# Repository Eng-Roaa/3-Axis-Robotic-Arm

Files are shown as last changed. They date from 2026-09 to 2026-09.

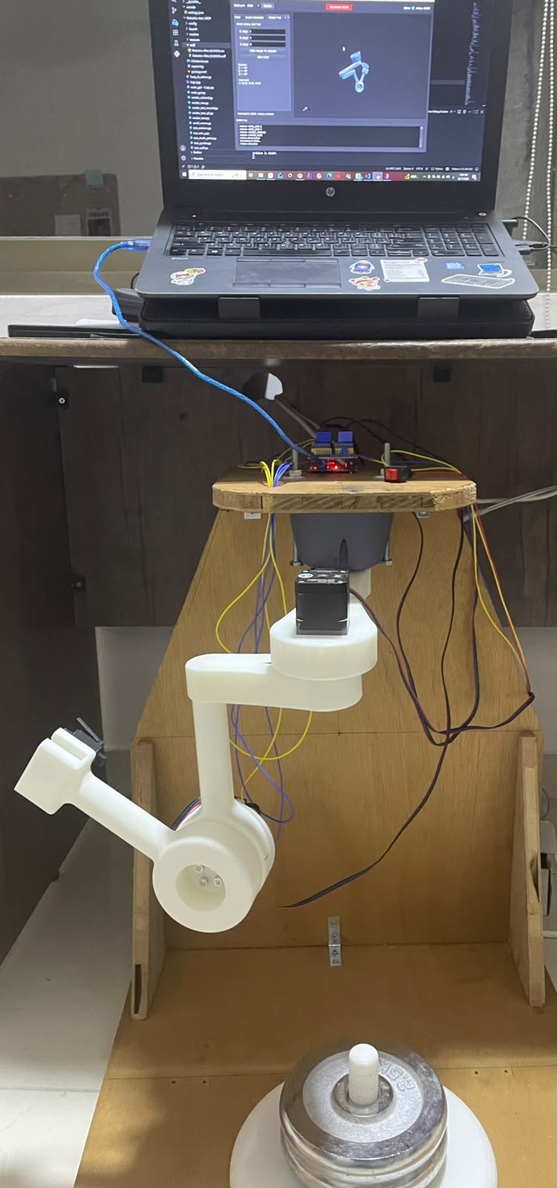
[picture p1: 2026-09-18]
Media/WhatsApp Image 2026-09-18 at 6.12.28 PM.jpeg

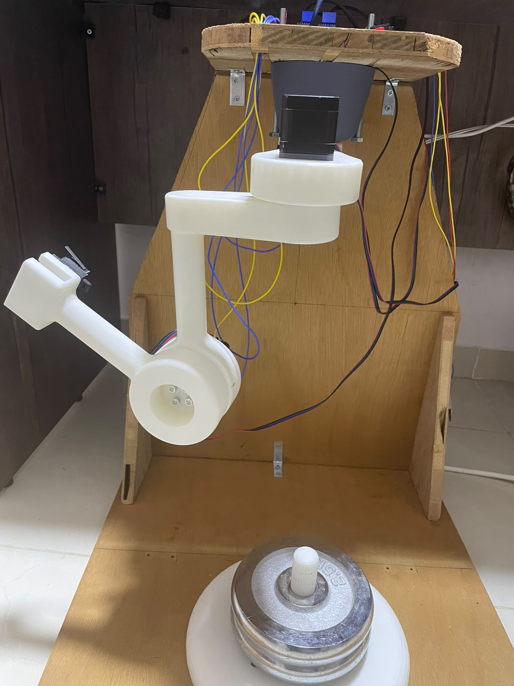
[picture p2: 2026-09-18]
Media/WhatsApp Image 2026-09-18 at 6.12.29 PM.jpeg

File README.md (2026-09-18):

# 3-Axis Robotic Arm | Design, Simulation, and Control 🦾

A 3-axis robotic arm developed as a complete robotics project, covering mechanical design, simulation, kinematics, hardware development, and motion control.

## 📌 Project Overview

The project started with the **CAD design** of the robotic arm and its mechanical components using **SolidWorks**. Before fabrication, the system was tested in a simulation environment to verify the robot's motion and kinematic calculations.

After validating the design and motion, the physical robotic arm was fabricated using **3D printing** and integrated with stepper motors and electronic control components.

## 🔹 CAD Design

The robotic arm and its mechanical components were designed using **SolidWorks**.

The design includes the main arm structure, joints, and **25:1 strain wave gearboxes** used with the stepper motors.

## 🔹 Simulation & Kinematics

A Python-based control system was developed to work with the robotic arm simulation.

The system implements:

* Forward Kinematics (FK)
* Inverse Kinematics (IK)
* Joint position control
* Robot motion simulation

The kinematic calculations were tested before moving to the physical implementation.

## 🔹 Hardware Development

After the simulation and testing stage, the robotic arm components and gearboxes were **3D-printed**.

### Main Hardware

* 3 × NEMA 17 Stepper Motors
* 3 × TMC2208 Stepper Motor Drivers
* CNC Shield V3
* Arduino
* 25:1 Strain Wave Gearboxes
* 3D-printed mechanical components
* 3 Limit switches

## 🔹 Motion Control

The robotic arm is controlled using a **Python application running on a PC**.

Python performs the main calculations, including forward and inverse kinematics, and sends the target joint angles to the **Arduino through serial communication**.

The Arduino then controls the stepper motors according to the received commands.

## 🔹 Synchronized Motion

A synchronized motion mechanism was implemented to ensure that the three motors **start and stop at the same time**, even when different angular movements are required for each joint.

This allows the joints to complete their movements together rather than having one motor finish earlier than the others.

## 🔹 Homing & Limit Switches

A homing procedure was implemented to establish a known starting position for the robotic arm.

**Limit switches** are used to detect the mechanical limits of the joints and stop the corresponding motion when the arm reaches the limit.

## 🛠️ Technologies Used

| Category | Technologies |
| --- | --- |
| CAD | SolidWorks |
| Programming | Python, Arduino/C++ |
| Control | Serial Communication |
| Kinematics | Forward & Inverse Kinematics |
| Motors | NEMA 17 Stepper Motors |
| Drivers | TMC2208 |
| Controller | Arduino + CNC Shield V3 |
| Manufacturing | 3D Printing |

## 📷 Project Media

Project images and videos are available in the `Media` folder.

## 🎥 Project Demonstration

A demonstration video of the robotic arm will be added here.
https://drive.google.com/file/d/13j7fY6XMhpEBEr_zSgsBxvps_PN-o1Ip/view?usp=drive_link

## 🚀 Future Improvements

* Improve positioning accuracy
* Implement smoother trajectory planning
* Add acceleration and deceleration profiles
* Improve the simulation environment
* Develop more advanced motion planning
* Improve the user interface

## 👩‍💻 Author

**Roaa Ghanem**

Biomedical Engineer

---

*This project was developed for educational and practical exploration of robotics, CAD, kinematics, and motion control.*

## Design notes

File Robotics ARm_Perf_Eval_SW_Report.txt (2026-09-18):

The following messages were automatically dismissed when this file was opened

File	Message	Response	

Servo_Motor.SLDPRT	One or more features in this part are based on other documents. If those documents have changed, they should be opened now to properly update this part.	Open any documents which have changed

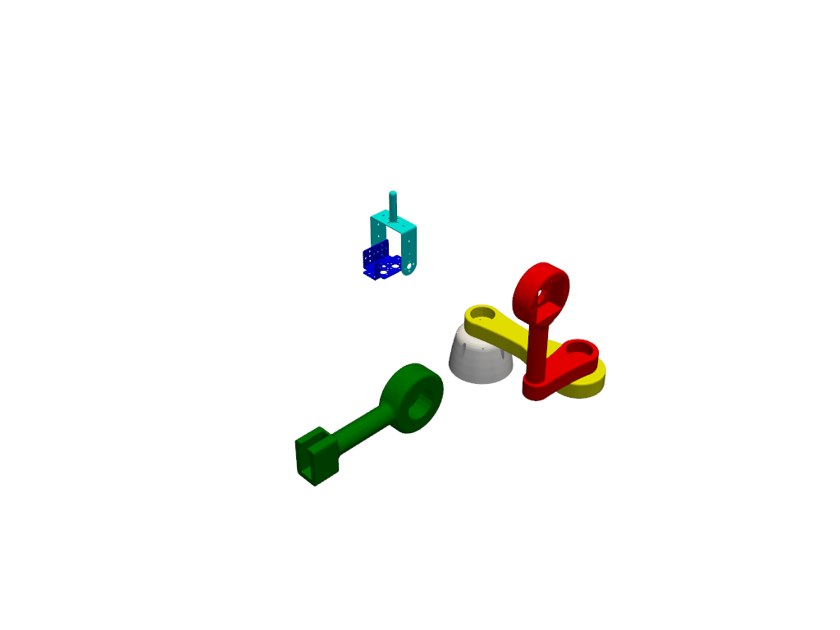
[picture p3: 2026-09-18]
fixed_arm.png

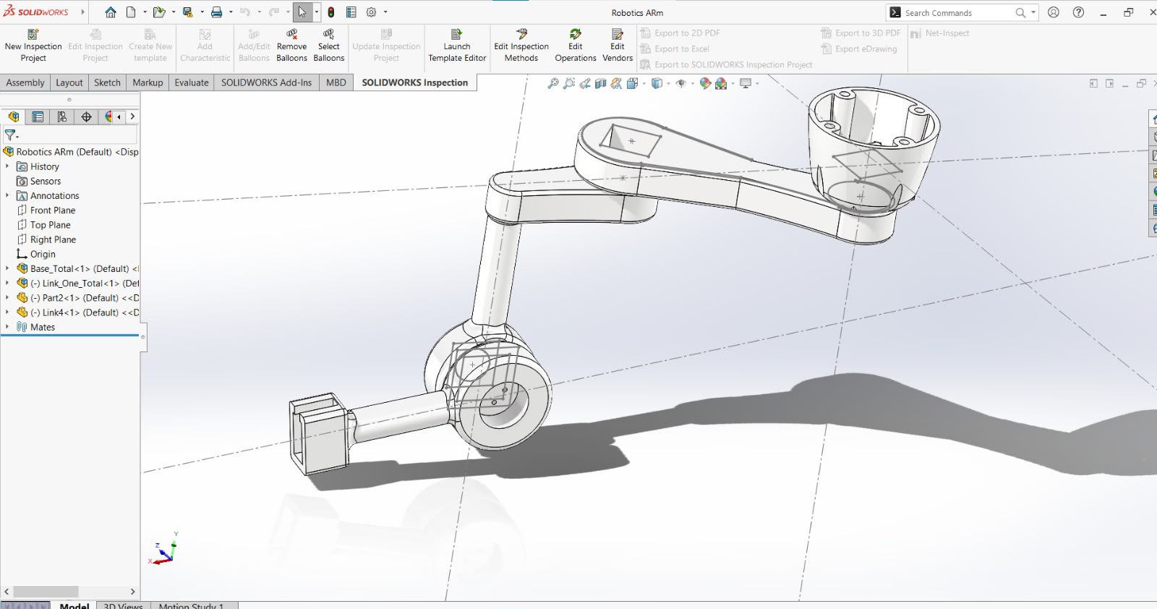
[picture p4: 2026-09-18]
Media/WhatsApp Image 2026-09-18 at 6.11.49 PM.jpeg

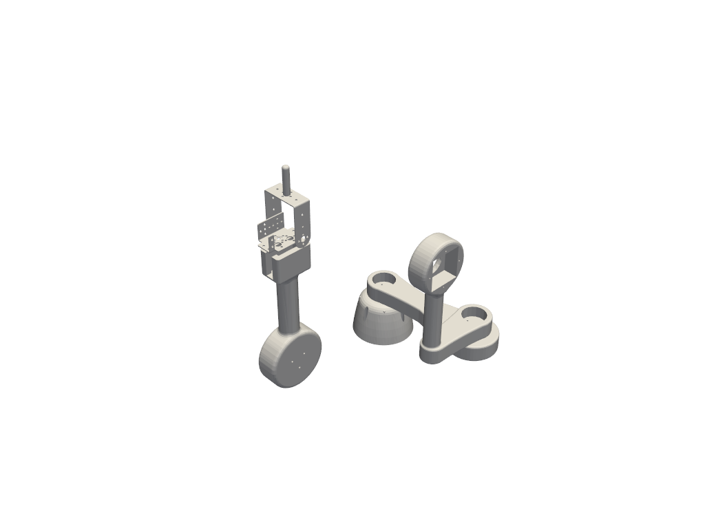
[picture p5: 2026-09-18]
moved_q2.png

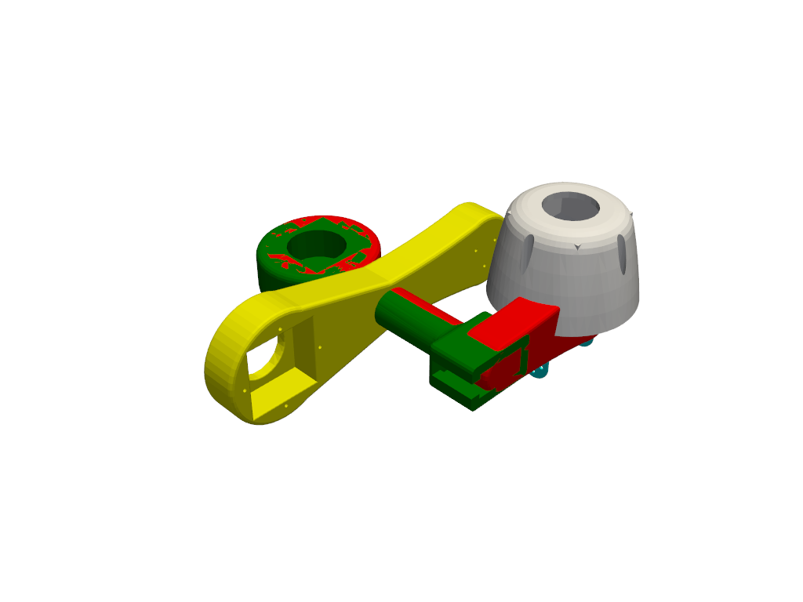
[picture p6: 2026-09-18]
raw_meshes.png

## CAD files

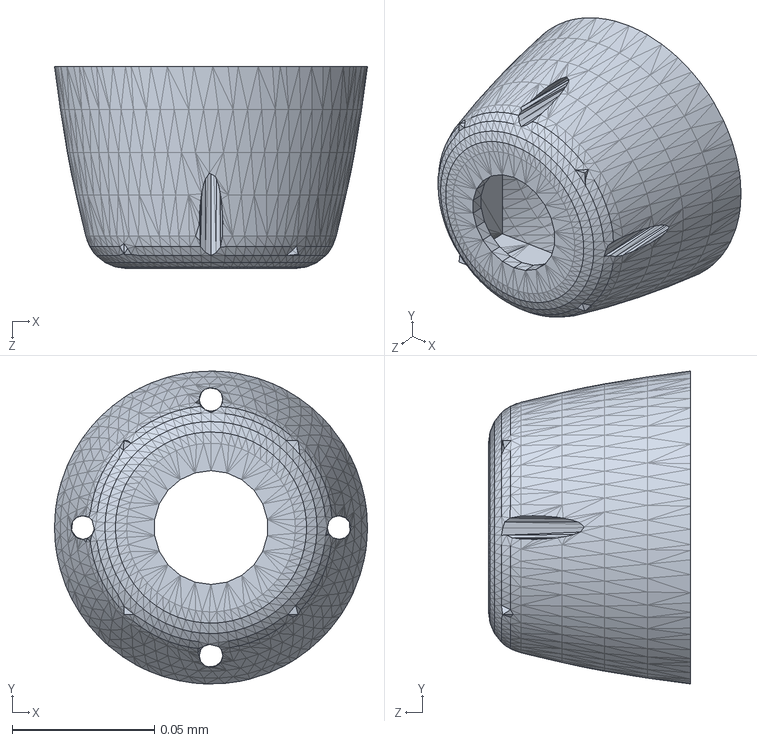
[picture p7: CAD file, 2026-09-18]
base_link.SLDPRT
0.11 x 0.11 x 0.071 mm

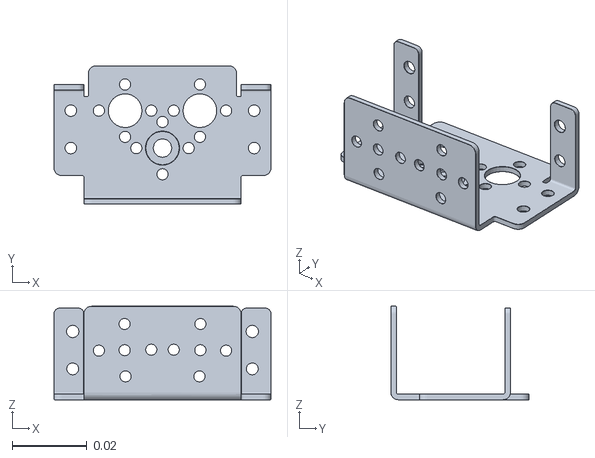
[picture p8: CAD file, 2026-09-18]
Robotics Arm URDF/meshes/Link_4.STL
0.058 x 0.037 x 0.025

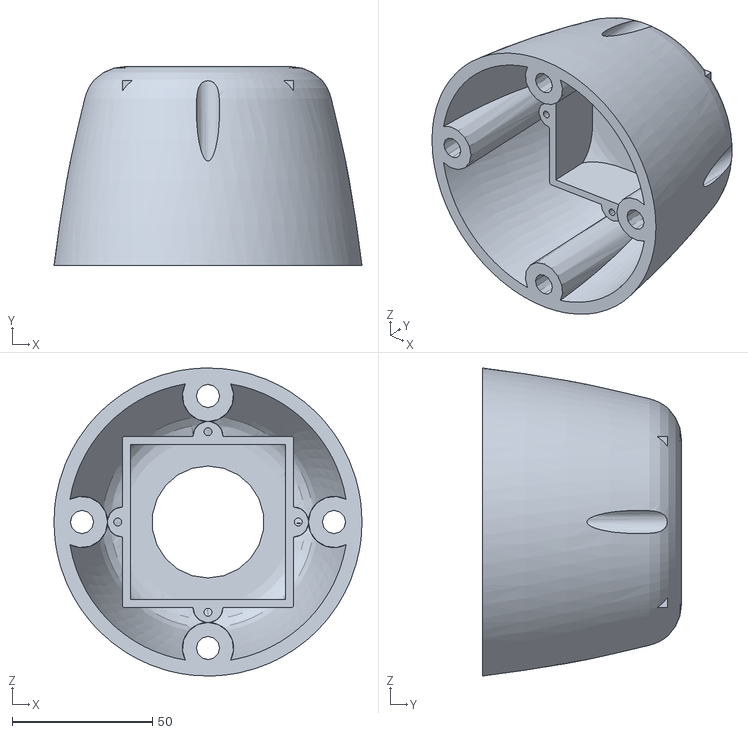
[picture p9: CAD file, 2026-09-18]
STL Files/Base.STL
110.0 x 71.0 x 110.0

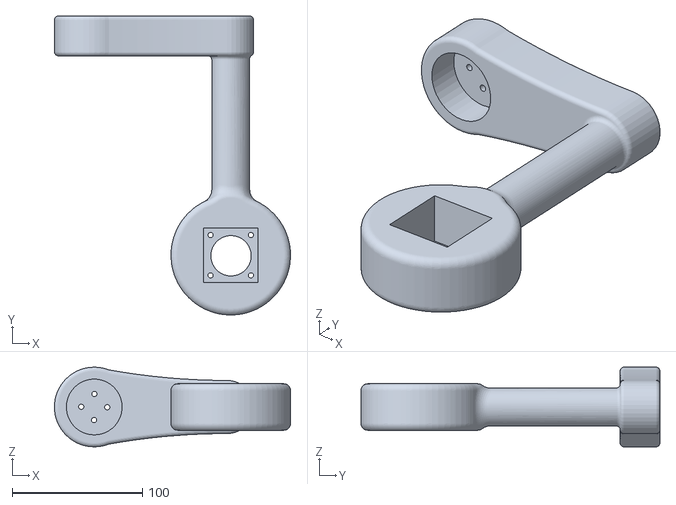
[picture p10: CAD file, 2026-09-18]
STL Files/robotic arm stl Fixed-Printable/Part2.STL
181.2 x 229.5 x 61.2

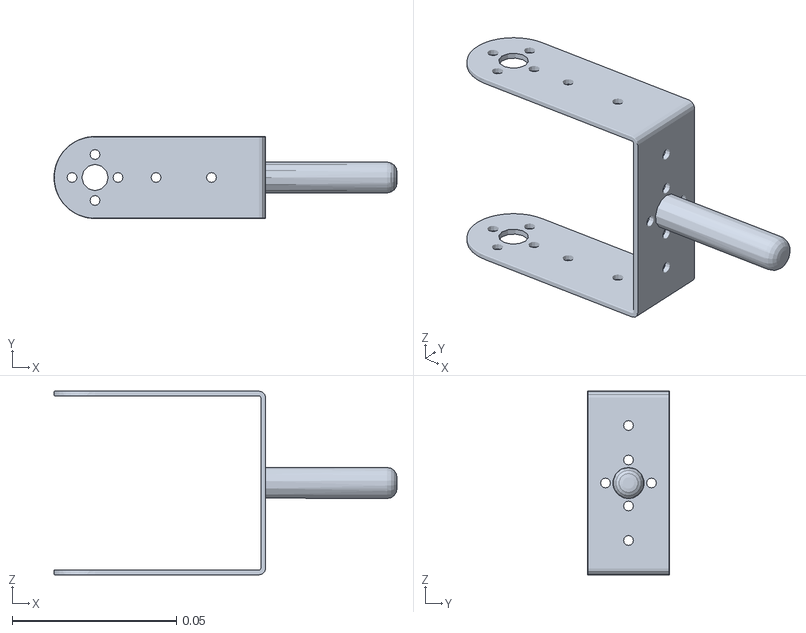
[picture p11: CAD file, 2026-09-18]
Robotics Arm URDF/meshes/Link_5.STL
0.104 x 0.025 x 0.056

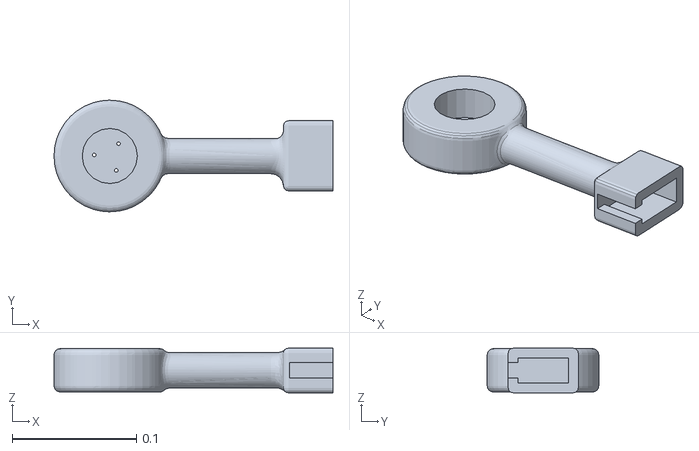
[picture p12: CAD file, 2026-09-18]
src - Copy/Robotics Arm URDF/meshes/Link_3.STL
0.225 x 0.09 x 0.036

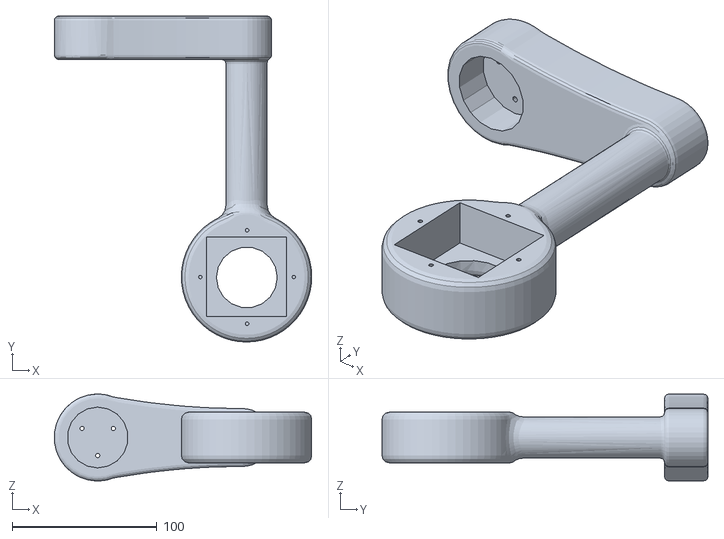
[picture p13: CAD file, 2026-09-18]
STL Files/Link_Two.STL
177.7 x 225.0 x 60.0

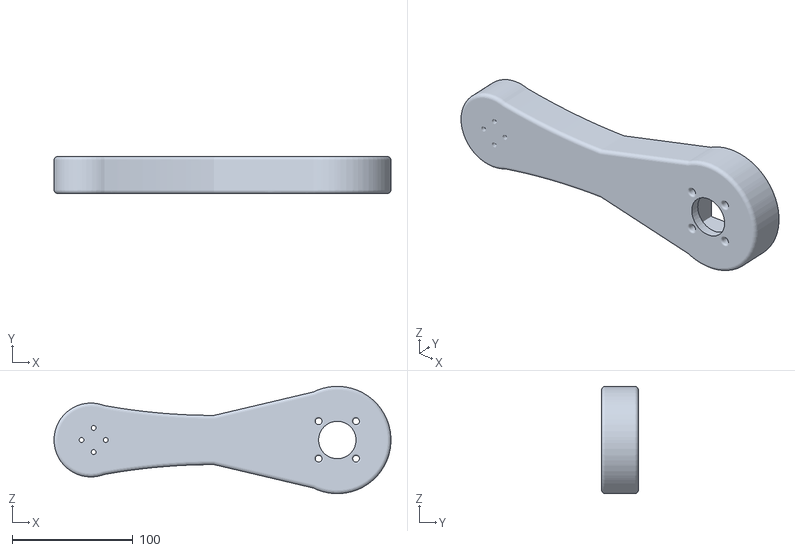
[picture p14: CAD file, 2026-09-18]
STL Files/robotic arm stl Fixed-Printable/Link_One_Base.STL
279.0 x 30.6 x 88.9

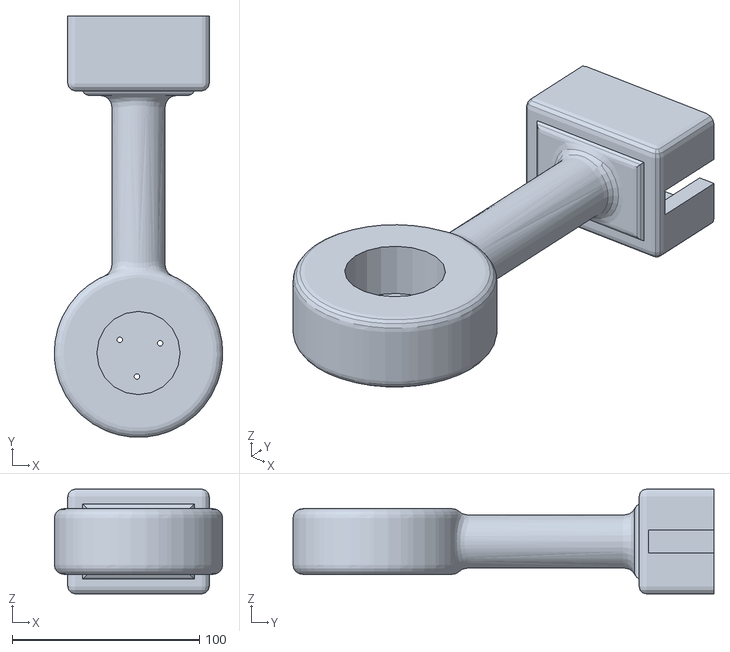
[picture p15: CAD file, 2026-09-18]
STL Files/Link_Three.STL
89.9 x 224.9 x 56.0

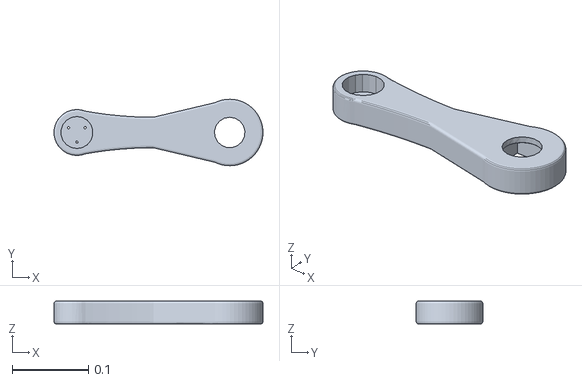
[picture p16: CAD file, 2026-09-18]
Robotics Arm URDF/meshes/Link_1.STL
0.274 x 0.0871 x 0.03

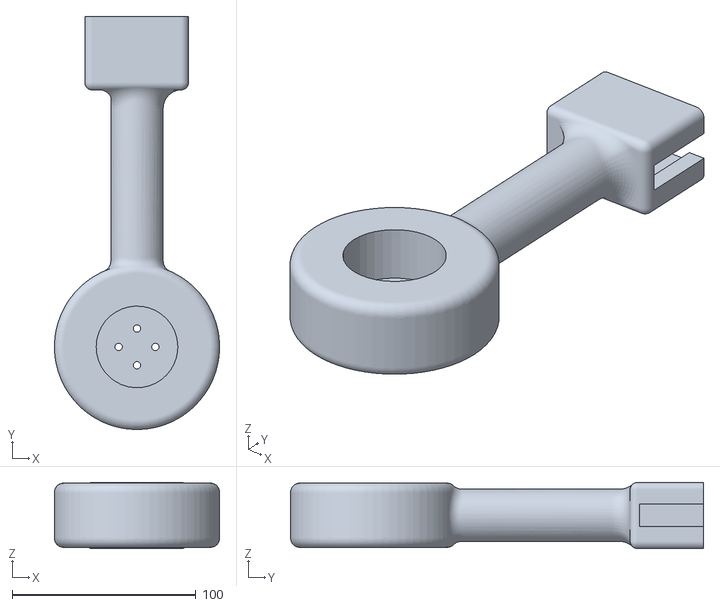
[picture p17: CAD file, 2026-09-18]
STL Files/robotic arm stl Fixed-Printable/Link4.STL
90.0 x 225.0 x 36.0

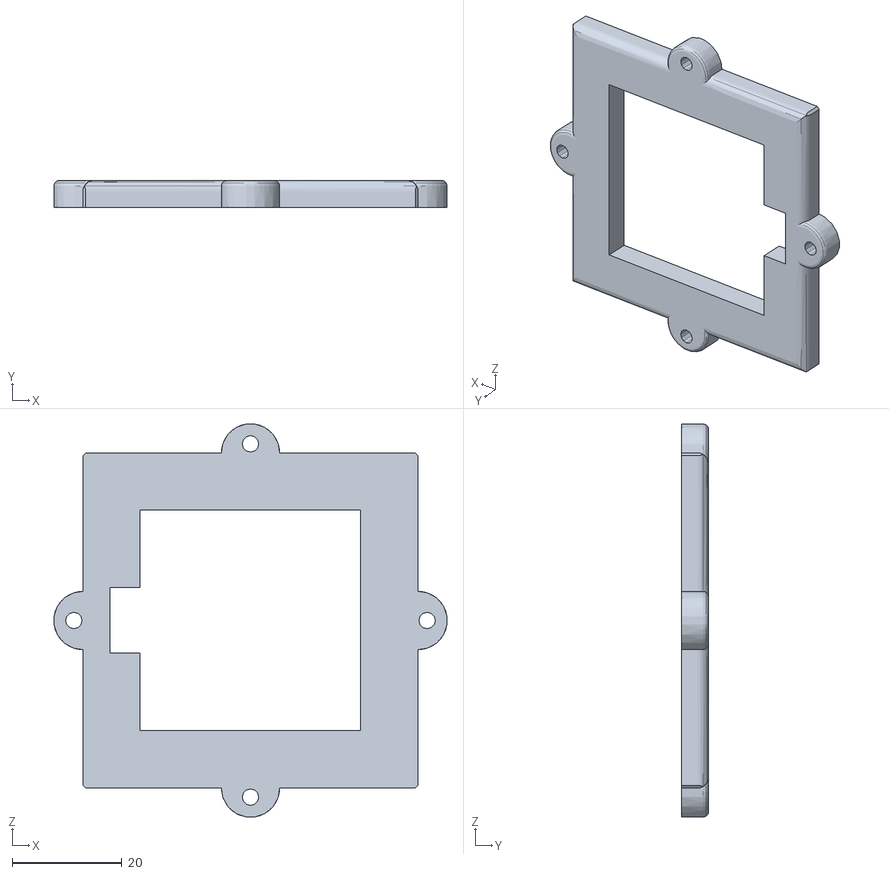
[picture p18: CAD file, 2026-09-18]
STL Files/Stepper1_Cover.STL
71.8 x 5.00 x 71.8

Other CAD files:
src - Copy/Robotics Arm URDF/meshes/base_link.STL
Robotics Arm URDF/meshes/base_link.STL
Robotics Arm URDF/meshes/Link_2.STL
STL Files/Link_One_Base.STL
src - Copy/Robotics Arm URDF/meshes/Link_2.STL

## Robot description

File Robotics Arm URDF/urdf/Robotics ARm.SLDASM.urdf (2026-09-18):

<?xml version="1.0" encoding="utf-8"?>
<!-- This URDF was automatically created by SolidWorks to URDF Exporter! Originally created by Stephen Brawner (brawner@gmail.com) 
     Commit Version: 1.6.0-1-g15f4949  Build Version: 1.6.7594.29634
     For more information, please see http://wiki.ros.org/sw_urdf_exporter -->
<robot name="Robotics ARm.SLDASM">
  <link name="base_link">
    <inertial>
      <origin xyz="-6.2091E-07 -2.0803E-07 0.03684" rpy="0 0 0" />
      <mass value="0.19876" />
      <inertia ixx="0.00027879" ixy="3.066E-10" ixz="-2.8839E-09" iyy="0.00027881" iyz="1.7174E-09" izz="0.00037557" />
    </inertial>
    <visual>
      <origin xyz="0 0 0" rpy="0 0 0" />
      <geometry>
        <mesh filename="package://Robotics ARm.SLDASM/meshes/base_link.STL" />
      </geometry>
      <material name="">
        <color rgba="1 1 1 1" />
      </material>
    </visual>
    <collision>
      <origin xyz="0 0 0" rpy="0 0 0" />
      <geometry>
        <mesh filename="package://Robotics ARm.SLDASM/meshes/base_link.STL" />
      </geometry>
    </collision>
  </link>
  <link name="Link_1">
    <inertial>
      <origin xyz="0.11311 2.6354E-07 0.014012" rpy="0 0 0" />
      <mass value="0.2771" />
      <inertia ixx="0.00015812" ixy="-1.3253E-08" ixz="-3.6214E-05" iyy="0.0020571" iyz="1.2096E-08" izz="0.0021618" />
    </inertial>
    <visual>
      <origin xyz="0 0 0" rpy="0 0 0" />
      <geometry>
        <mesh filename="package://Robotics ARm.SLDASM/meshes/Link_1.STL" />
      </geometry>
      <material name="">
        <color rgba="1 1 1 1" />
      </material>
    </visual>
    <collision>
      <origin xyz="0 0 0" rpy="0 0 0" />
      <geometry>
        <mesh filename="package://Robotics ARm.SLDASM/meshes/Link_1.STL" />
      </geometry>
    </collision>
  </link>
  <joint name="Joint_1" type="revolute">
    <origin xyz="0 0 0.074" rpy="0 0 0" />
    <parent link="base_link" />
    <child link="Link_1" />
    <axis xyz="0 0 -1" />
    <limit lower="0" upper="6.28" effort="0.57" velocity="31" />
  </joint>
  <link name="Link_2">
    <inertial>
      <origin xyz="0.079229 -0.00068237 0.10093" rpy="0 0 0" />
      <mass value="0.39142" />
      <inertia ixx="0.0023925" ixy="6.2334E-06" ixz="-0.00081246" iyy="0.0031163" iyz="2.1024E-05" izz="0.00083966" />
    </inertial>
    <visual>
      <origin xyz="0 0 0" rpy="0 0 0" />
      <geometry>
        <mesh filename="package://Robotics ARm.SLDASM/meshes/Link_2.STL" />
      </geometry>
      <material name="">
        <color rgba="1 1 1 1" />
      </material>
    </visual>
    <collision>
      <origin xyz="0 0 0" rpy="0 0 0" />
      <geometry>
        <mesh filename="package://Robotics ARm.SLDASM/meshes/Link_2.STL" />
      </geometry>
    </collision>
  </link>
  <joint name="Joint_2" type="revolute">
    <origin xyz="0.2 0 0.033" rpy="0 0 -2.618" />
    <parent link="Link_1" />
    <child link="Link_2" />
    <axis xyz="0 0 1" />
    <limit lower="0" upper="4.71" effort="0.57" velocity="31" />
  </joint>
  <link name="Link_3">
    <inertial>
      <origin xyz="0.046044 0.00029864 0.016784" rpy="0 0 0" />
      <mass value="0.37842" />
      <inertia ixx="0.00019779" ixy="-1.3253E-05" ixz="-1.0873E-05" iyy="0.0017145" iyz="-7.9146E-08" izz="0.0018358" />
    </inertial>
    <visual>
      <origin xyz="0 0 0" rpy="0 0 0" />
      <geometry>
        <mesh filename="package://Robotics ARm.SLDASM/meshes/Link_3.STL" />
      </geometry>
      <material name="">
        <color rgba="1 1 1 1" />
      </material>
    </visual>
    <collision>
      <origin xyz="0 0 0" rpy="0 0 0" />
      <geometry>
        <mesh filename="package://Robotics ARm.SLDASM/meshes/Link_3.STL" />
      </geometry>
    </collision>
  </link>
  <joint name="Joint_3" type="revolute">
    <origin xyz="0.10292 -0.0205 0.18044" rpy="1.5708 0.7854 0" />
    <parent link="Link_2" />
    <child link="Link_3" />
    <axis xyz="0 0 1" />
    <limit lower="0" upper="3.14" effort="0.57" velocity="31" />
  </joint>
  <link name="Link_4">
    <inertial>
      <origin xyz="5.5511E-17 -0.00087981 0.0061517" rpy="0 0 0" />
      <mass value="0.0055261" />
      <inertia ixx="1.2093E-06" ixy="-3.8646E-21" ixz="8.9997E-22" iyy="1.7956E-06" iyz="1.6184E-07" izz="2.3593E-06" />
    </inertial>
    <visual>
      <origin xyz="0 0 0" rpy="0 0 0" />
      <geometry>
        <mesh filename="package://Robotics ARm.SLDASM/meshes/Link_4.STL" />
      </geometry>
      <material name="">
        <color rgba="1 1 1 1" />
      </material>
    </visual>
    <collision>
      <origin xyz="0 0 0" rpy="0 0 0" />
      <geometry>
        <mesh filename="package://Robotics ARm.SLDASM/meshes/Link_4.STL" />
      </geometry>
    </collision>
  </link>
  <joint name="Joint_4" type="revolute">
    <origin xyz="0.19566 -0.010079 0.017341" rpy="-1.5708 0 -1.5708" />
    <parent link="Link_3" />
    <child link="Link_4" />
    <axis xyz="0 0 1" />
    <limit lower="0" upper="6.28" effort="0.57" velocity="31" />
  </joint>
  <link name="Link_5">
    <inertial>
      <origin xyz="0.043382 2.0817E-17 0" rpy="0 0 0" />
      <mass value="0.011523" />
      <inertia ixx="5.1842E-06" ixy="9.7409E-21" ixz="2.1176E-21" iyy="1.2521E-05" iyz="-3.5999E-21" izz="8.223E-06" />
    </inertial>
    <visual>
      <origin xyz="0 0 0" rpy="0 0 0" />
      <geometry>
        <mesh filename="package://Robotics ARm.SLDASM/meshes/Link_5.STL" />
      </geometry>
      <material name="">
        <color rgba="1 1 1 1" />
      </material>
    </visual>
    <collision>
      <origin xyz="0 0 0" rpy="0 0 0" />
      <geometry>
        <mesh filename="package://Robotics ARm.SLDASM/meshes/Link_5.STL" />
      </geometry>
    </collision>
  </link>
  <joint name="Joint_5" type="revolute">
    <origin xyz="-0.011 0.00327 0.0115" rpy="1.5708 0 0" />
    <parent link="Link_4" />
    <child link="Link_5" />
    <axis xyz="0 0 1" />
    <limit lower="0" upper="3.14" effort="0.57" velocity="31" />
  </joint>
</robot>

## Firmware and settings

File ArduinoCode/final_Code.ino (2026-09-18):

// ============================================================
// 3-AXIS ROBOT ARM
// Arduino + CNC Shield V3 + TMC2208
// Python Serial Control
//
// Commands from Python:
//
// HOME
//
// A,j1,j2,j3
// Example:
// A,-30.00,-45.00,-10.00
// ============================================================


// ============================================================
// MOTOR PINS
// ============================================================

const int STEP1 = 2;
const int DIR1  = 5;

const int STEP2 = 3;
const int DIR2  = 6;

const int STEP3 = 4;
const int DIR3  = 7;

const int EN = 8;


// ============================================================
// LIMIT SWITCHES
// ============================================================

const int LIMIT_X = 9;
const int LIMIT_Y = 10;
const int LIMIT_Z = 11;


// ============================================================
// MOTOR PARAMETERS
// ============================================================

const float steps = 200.0;

const float gearboxreduction = 25.0;

const float microstepFactor = 9.6;


// ============================================================
// HOMING
// ============================================================

const int HOME_DIR = HIGH;

const unsigned long HOMING_DELAY = 1000;

const long MAX_HOMING_STEPS = 100000;


// ============================================================
// CURRENT ANGLES
// ============================================================

float currentAngle1 = 0.0;
float currentAngle2 = 0.0;
float currentAngle3 = 0.0;


// ============================================================
// SOFTWARE LIMITS
// ============================================================

const float MIN_ANGLE1 = -120.0;
const float MIN_ANGLE2 = -180.0;
const float MIN_ANGLE3 = -120.0;

const float MAX_ANGLE1 = 0.0;
const float MAX_ANGLE2 = 0.0;
const float MAX_ANGLE3 = 0.0;


// ============================================================
// SERIAL BUFFER
// ============================================================

String inputString = "";


// ============================================================
// SETUP
// ============================================================

void setup()
{
  Serial.begin(9600);

  // ==========================================================
  // MOTOR PINS
  // ==========================================================

  pinMode(STEP1, OUTPUT);
  pinMode(DIR1, OUTPUT);

  pinMode(STEP2, OUTPUT);
  pinMode(DIR2, OUTPUT);

  pinMode(STEP3, OUTPUT);
  pinMode(DIR3, OUTPUT);


  // ==========================================================
  // ENABLE
  // ==========================================================

  pinMode(EN, OUTPUT);

  // CNC Shield V3:
  // LOW = Enable motors

  digitalWrite(EN, LOW);


  // ==========================================================
  // LIMIT SWITCHES
  // ==========================================================

  pinMode(LIMIT_X, INPUT_PULLUP);
  pinMode(LIMIT_Y, INPUT_PULLUP);
  pinMode(LIMIT_Z, INPUT_PULLUP);


  // ==========================================================
  // INITIAL STEP STATE
  // ==========================================================

  digitalWrite(STEP1, LOW);
  digitalWrite(STEP2, LOW);
  digitalWrite(STEP3, LOW);


  delay(500);


  Serial.println("STARTING");


  // ==========================================================
  // AUTOMATIC HOMING
  //
  // ALL 3 MOTORS MOVE TOGETHER
  // ==========================================================

  Home_All_Axes();


  // ==========================================================
  // RESET CURRENT ANGLES
  // ==========================================================

  currentAngle1 = 0.0;
  currentAngle2 = 0.0;
  currentAngle3 = 0.0;


  Serial.println("HOMING_DONE");
  Serial.println("READY");
}


// ============================================================
// LOOP
// ============================================================

void loop()
{
  // ----------------------------------------------------------
  // Receive commands from Python
  // ----------------------------------------------------------

  if (Serial.available() > 0)
  {
    inputString = Serial.readStringUntil('\n');

    inputString.trim();

    if (inputString.length() > 0)
    {
      processCommand(inputString);
    }
  }
}


// ============================================================
// PROCESS SERIAL COMMAND
// ============================================================

void processCommand(String command)
{
  command.trim();


  // ==========================================================
  // HOME COMMAND
  // ==========================================================

  if (command.equalsIgnoreCase("HOME"))
  {
    Serial.println("HOME_COMMAND_RECEIVED");


    // --------------------------------------------------------
    // Home all three motors simultaneously
    // --------------------------------------------------------

    Home_All_Axes();


    // --------------------------------------------------------
    // Reset angles
    // --------------------------------------------------------

    currentAngle1 = 0.0;
    currentAngle2 = 0.0;
    currentAngle3 = 0.0;


    Serial.println("HOMING_DONE");


    return;
  }


  // ==========================================================
  // ANGLE COMMAND
  //
  // A,j1,j2,j3
  // ==========================================================

  if (command.startsWith("A,"))
  {
    String data = command.substring(2);


    int comma1 = data.indexOf(',');

    if (comma1 < 0)
    {
      Serial.println("ERROR,BAD_FORMAT");
      return;
    }


    int comma2 = data.indexOf(
      ',',
      comma1 + 1
    );

    if (comma2 < 0)
    {
      Serial.println("ERROR,BAD_FORMAT");
      return;
    }


    String s1 = data.substring(
      0,
      comma1
    );

    String s2 = data.substring(
      comma1 + 1,
      comma2
    );

    String s3 = data.substring(
      comma2 + 1
    );


    float target1 = s1.toFloat();
    float target2 = s2.toFloat();
    float target3 = s3.toFloat();


    // --------------------------------------------------------
    // Print targets
    // --------------------------------------------------------

    Serial.print("TARGETS: ");

    Serial.print(target1);

    Serial.print(", ");

    Serial.print(target2);

    Serial.print(", ");

    Serial.println(target3);


    // ========================================================
    // SOFTWARE LIMIT J1
    // ========================================================

    if (
      target1 < MIN_ANGLE1 ||
      target1 > MAX_ANGLE1
    )
    {
      Serial.println("ERROR,J1_LIMIT");
      return;
    }


    // ========================================================
    // SOFTWARE LIMIT J2
    // ========================================================

    if (
      target2 < MIN_ANGLE2 ||
      target2 > MAX_ANGLE2
    )
    {
      Serial.println("ERROR,J2_LIMIT");
      return;
    }


    // ========================================================
    // SOFTWARE LIMIT J3
    // ========================================================

    if (
      target3 < MIN_ANGLE3 ||
      target3 > MAX_ANGLE3
    )
    {
      Serial.println("ERROR,J3_LIMIT");
      return;
    }


    // ========================================================
    // MOVE
    // ========================================================

    MoveToAngles(
      target1,
      target2,
      target3
    );


    Serial.println("DONE");


    return;
  }


  // ==========================================================
  // UNKNOWN COMMAND
  // ==========================================================

  Serial.println("ERROR,UNKNOWN_COMMAND");
}


// ============================================================
// ANGLE TO STEPS
// ============================================================

long Angle_Converter(float angle)
{
  float result =
    (
      abs(angle)
      *
      steps
      *
      gearboxreduction
      *
      microstepFactor
    )
    / 360.0;


  return (long)result;
}


// ============================================================
// MOVE TO TARGET ANGLES
//
// J1 + J2 + J3 move synchronously
// ============================================================

void MoveToAngles(
  float target1,
  float target2,
  float target3
)
{
  // ----------------------------------------------------------
  // Calculate angle differences
  // ----------------------------------------------------------

  float delta1 =
    target1 - currentAngle1;

  float delta2 =
    target2 - currentAngle2;

  float delta3 =
    target3 - currentAngle3;


  // ----------------------------------------------------------
  // Directions
  // ----------------------------------------------------------

  bool dir1 =
    (delta1 >= 0)
    ? HIGH
    : LOW;

  bool dir2 =
    (delta2 >= 0)
    ? HIGH
    : LOW;

  bool dir3 =
    (delta3 >= 0)
    ? HIGH
    : LOW;


  // ----------------------------------------------------------
  // Set directions BEFORE stepping
  // ----------------------------------------------------------

  digitalWrite(
    DIR1,
    dir1
  );

  digitalWrite(
    DIR2,
    dir2
  );

  digitalWrite(
    DIR3,
    dir3
  );


  // ----------------------------------------------------------
  // Calculate number of steps
  // ----------------------------------------------------------

  long steps1 =
    Angle_Converter(delta1);

  long steps2 =
    Angle_Converter(delta2);

  long steps3 =
    Angle_Converter(delta3);


  // ----------------------------------------------------------
  // Find maximum steps
  // ----------------------------------------------------------

  long maxSteps =
    max(
      steps1,
      max(
        steps2,
        steps3
      )
    );


  if (maxSteps <= 0)
  {
    return;
  }


  // ----------------------------------------------------------
  // Calculate movement ratios
  // ----------------------------------------------------------

  float ratio1 =
    (float)steps1 / maxSteps;

  float ratio2 =
    (float)steps2 / maxSteps;

  float ratio3 =
    (float)steps3 / maxSteps;


  float accum1 = 0.0;
  float accum2 = 0.0;
  float accum3 = 0.0;


  // ----------------------------------------------------------
  // Stop flags
  // ----------------------------------------------------------

  bool stop1 = false;
  bool stop2 = false;
  bool stop3 = false;


  // ==========================================================
  // SYNCHRONIZED MOVEMENT
  // ==========================================================

  for (
    long i = 0;
    i < maxSteps;
    i++
  )
  {

    // ========================================================
    // LIMIT CHECK J1
    // ========================================================

    if (
      digitalRead(LIMIT_X) == LOW &&
      dir1 == HIGH &&
      !stop1
    )
    {
      stop1 = true;

      currentAngle1 = 0.0;

      Serial.println("LIMIT,X");
    }


    // ========================================================
    // LIMIT CHECK J2
    // ========================================================

    if (
      digitalRead(LIMIT_Y) == LOW &&
      dir2 == HIGH &&
      !stop2
    )
    {
      stop2 = true;

      currentAngle2 = 0.0;

      Serial.println("LIMIT,Y");
    }


    // ========================================================
    // LIMIT CHECK J3
    // ========================================================

    if (
      digitalRead(LIMIT_Z) == LOW &&
      dir3 == HIGH &&
      !stop3
    )
    {
      stop3 = true;

      currentAngle3 = 0.0;

      Serial.println("LIMIT,Z");
    }


    // ========================================================
    // MOTOR 1
    // ========================================================

    accum1 += ratio1;

    if (
      accum1 >= 1.0 &&
      !stop1 &&
      steps1 > 0
    )
    {
      digitalWrite(
        STEP1,
        HIGH
      );

      delayMicroseconds(
        HOMING_DELAY
      );

      digitalWrite(
        STEP1,
        LOW
      );

      delayMicroseconds(
        HOMING_DELAY
      );

      accum1 -= 1.0;
    }


    // ========================================================
    // MOTOR 2
    // ========================================================

    accum2 += ratio2;

    if (
      accum2 >= 1.0 &&
      !stop2 &&
      steps2 > 0
    )
    {
      digitalWrite(
        STEP2,
        HIGH
      );

      delayMicroseconds(
        HOMING_DELAY
      );

      digitalWrite(
        STEP2,
        LOW
      );

      delayMicroseconds(
        HOMING_DELAY
      );

      accum2 -= 1.0;
    }


    // ========================================================
    // MOTOR 3
    // ========================================================

    accum3 += ratio3;

    if (
      accum3 >= 1.0 &&
      !stop3 &&
      steps3 > 0
    )
    {
      digitalWrite(
        STEP3,
        HIGH
      );

      delayMicroseconds(
        HOMING_DELAY
      );

      digitalWrite(
        STEP3,
        LOW
      );

      delayMicroseconds(
        HOMING_DELAY
      );

      accum3 -= 1.0;
    }
  }


  // ----------------------------------------------------------
  // Update current angles
  // ----------------------------------------------------------

  if (!stop1)
  {
    currentAngle1 = target1;
  }

  if (!stop2)
  {
    currentAngle2 = target2;
  }

  if (!stop3)
  {
    currentAngle3 = target3;
  }
}


// ============================================================
// HOME ALL AXES
//
// IMPORTANT:
//
// J1 + J2 + J3 START TOGETHER.
//
// Each motor stops when its own limit switch is reached.
//
// The function finishes only when ALL 3 motors
// have reached their limit switches.
//
// ============================================================

void Home_All_Axes()
{
  Serial.println("HOMING_START");


  // ==========================================================
  // SET HOME DIRECTION FOR ALL MOTORS FIRST
  // ==========================================================

  digitalWrite(
    DIR1,
    HOME_DIR
  );

  digitalWrite(
    DIR2,
    HOME_DIR
  );

  digitalWrite(
    DIR3,
    HOME_DIR
  );


  // ==========================================================
  // HOMING COUNTERS
  // ==========================================================

  long counter1 = 0;
  long counter2 = 0;
  long counter3 = 0;


  // ==========================================================
  // HOMING STOP FLAGS
  //
  // false = motor still moving
  // true  = motor reached limit
  // ==========================================================

  bool home1_done = false;
  bool home2_done = false;
  bool home3_done = false;


  // ==========================================================
  // CHECK IF A LIMIT SWITCH IS ALREADY PRESSED
  // ==========================================================

  if (digitalRead(LIMIT_X) == LOW)
  {
    home1_done = true;

    Serial.println("HOME_LIMIT,X_ALREADY");
  }

  if (digitalRead(LIMIT_Y) == LOW)
  {
    home2_done = true;

    Serial.println("HOME_LIMIT,Y_ALREADY");
  }

  if (digitalRead(LIMIT_Z) == LOW)
  {
    home3_done = true;

    Serial.println("HOME_LIMIT,Z_ALREADY");
  }


  // ==========================================================
  // ALL THREE MOTORS MOVE TOGETHER
  // ==========================================================

  while (
    !home1_done ||
    !home2_done ||
    !home3_done
  )
  {

    // ========================================================
    // CHECK LIMIT X / J1
    // ========================================================

    if (!home1_done)
    {
      if (
        digitalRead(LIMIT_X) == LOW
      )
      {
        home1_done = true;

        currentAngle1 = 0.0;

        digitalWrite(
          STEP1,
          LOW
        );

        Serial.println(
          "HOME_LIMIT,X"
        );
      }
    }


    // ========================================================
    // CHECK LIMIT Y / J2
    // ========================================================

    if (!home2_done)
    {
      if (
        digitalRead(LIMIT_Y) == LOW
      )
      {
        home2_done = true;

        currentAngle2 = 0.0;

        digitalWrite(
          STEP2,
          LOW
        );

        Serial.println(
          "HOME_LIMIT,Y"
        );
      }
    }


    // ========================================================
    // CHECK LIMIT Z / J3
    // ========================================================

    if (!home3_done)
    {
      if (
        digitalRead(LIMIT_Z) == LOW
      )
      {
        home3_done = true;

        currentAngle3 = 0.0;

        digitalWrite(
          STEP3,
          LOW
        );

        Serial.println(
          "HOME_LIMIT,Z"
        );
      }
    }


    // ========================================================
    // J1 STEP
    //
    // J1 continues only if it has NOT reached its limit.
    // ========================================================

    if (
      !home1_done &&
      counter1 < MAX_HOMING_STEPS
    )
    {
      digitalWrite(
        STEP1,
        HIGH
      );
    }


    // ========================================================
    // J2 STEP
    //
    // J2 continues only if it has NOT reached its limit.
    // ========================================================

    if (
      !home2_done &&
      counter2 < MAX_HOMING_STEPS
    )
    {
      digitalWrite(
        STEP2,
        HIGH
      );
    }


    // ========================================================
    // J3 STEP
    //
    // J3 continues only if it has NOT reached its limit.
    // ========================================================

    if (
      !home3_done &&
      counter3 < MAX_HOMING_STEPS
    )
    {
      digitalWrite(
        STEP3,
        HIGH
      );
    }


    // ========================================================
    // HIGH PULSE
    //
    // All active motors receive the HIGH pulse together.
    // ========================================================

    delayMicroseconds(
      HOMING_DELAY
    );


    // ========================================================
    // STEP LOW
    // ========================================================

    if (!home1_done)
    {
      digitalWrite(
        STEP1,
        LOW
      );
    }

    if (!home2_done)
    {
      digitalWrite(
        STEP2,
        LOW
      );
    }

    if (!home3_done)
    {
      digitalWrite(
        STEP3,
        LOW
      );
    }


    // ========================================================
    // LOW PULSE DELAY
    // ========================================================

    delayMicroseconds(
      HOMING_DELAY
    );


    // ========================================================
    // INCREMENT COUNTERS
    // ========================================================

    if (!home1_done)
    {
      counter1++;
    }

    if (!home2_done)
    {
      counter2++;
    }

    if (!home3_done)
    {
      counter3++;
    }


    // ========================================================
    // MAXIMUM STEP SAFETY
    //
    // If a motor cannot find its switch after
    // MAX_HOMING_STEPS, stop it.
    // ========================================================

    if (
      counter1 >= MAX_HOMING_STEPS &&
      !home1_done
    )
    {
      home1_done = true;

      digitalWrite(
        STEP1,
        LOW
      );

      Serial.println(
        "ERROR,HOMING_TIMEOUT_X"
      );
    }


    if (
      counter2 >= MAX_HOMING_STEPS &&
      !home2_done
    )
    {
      home2_done = true;

      digitalWrite(
        STEP2,
        LOW
      );

      Serial.println(
        "ERROR,HOMING_TIMEOUT_Y"
      );
    }


    if (
      counter3 >= MAX_HOMING_STEPS &&
      !home3_done
    )
    {
      home3_done = true;

      digitalWrite(
        STEP3,
        LOW
      );

      Serial.println(
        "ERROR,HOMING_TIMEOUT_Z"
      );
    }
  }


  // ==========================================================
  // MAKE SURE ALL STEP PINS ARE LOW
  // ==========================================================

  digitalWrite(
    STEP1,
    LOW
  );

  digitalWrite(
    STEP2,
    LOW
  );

  digitalWrite(
    STEP3,
    LOW
  );


  // ==========================================================
  // RESET CURRENT ANGLES
  // ==========================================================

  currentAngle1 = 0.0;
  currentAngle2 = 0.0;
  currentAngle3 = 0.0;


  // ==========================================================
  // HOMING FINISHED
  //
  // This is printed ONLY after ALL THREE axes stopped.
  // ==========================================================

  Serial.println(
    "HOMING_FINISHED"
  );
}

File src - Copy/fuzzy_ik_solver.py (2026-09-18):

import numpy as np
import roboticstoolbox as rtb


class FuzzyIKSolver:

    def __init__(self, robot: rtb.Robot):

        self.robot = robot

    # ---------------------------------------------------------
    # FUZZIFICATION
    # ---------------------------------------------------------

    def fuzzify_error(
        self,
        error_val,
        max_err=1.0
    ):

        e = np.clip(
            abs(error_val) / max_err,
            0,
            1
        )

        small = (
            max(0, 1 - 2 * e)
            if e < 0.5
            else 0
        )

        medium = max(
            0,
            1 - abs(2 * e - 1)
        )

        large = (
            max(0, 2 * e - 1)
            if e > 0.5
            else 0
        )

        return (
            small,
            medium,
            large
        )

    # ---------------------------------------------------------
    # FUZZY GAIN
    # ---------------------------------------------------------

    def fuzzy_gain_rules(
        self,
        small,
        medium,
        large
    ):

        out_small = 0.05
        out_medium = 0.2
        out_large = 0.5

        numerator = (
            small * out_small
            + medium * out_medium
            + large * out_large
        )

        denominator = (
            small
            + medium
            + large
        )

        if denominator == 0:

            return out_small

        return numerator / denominator

    # ---------------------------------------------------------
    # IK SOLVER
    # ---------------------------------------------------------

    def solve_ik(
        self,
        target_pose,
        q0,
        max_iter=200,
        tol=1e-3,
        restarts=5
    ):

        # First try Robotics Toolbox LM solver
        try:

            sol = self.robot.ikine_LM(
                target_pose,
                q0=q0,
                joint_limits=True
            )

            if sol.success:

                return sol.q, True

        except Exception as e:

            print(
                "RTB IK failed:",
                e
            )

        # -----------------------------------------------------
        # Fuzzy iterative solver
        # -----------------------------------------------------

        best_q = np.copy(q0)

        min_pos_err = float("inf")

        for attempt in range(
            restarts + 1
        ):

            if attempt == 0:

                q = np.copy(q0)

            else:

                if self.robot.qlim is not None:

                    q = np.random.uniform(
                        self.robot.qlim[0],
                        self.robot.qlim[1]
                    )

                else:

                    q = np.random.uniform(
                        -np.pi,
                        np.pi,
                        self.robot.n
                    )

            for _ in range(max_iter):

                T_current = (
                    self.robot.fkine(q)
                )

                error_vector = np.concatenate(
                    [
                        target_pose.t
                        - T_current.t,

                        target_pose.rpy()
                        - T_current.rpy()
                    ]
                )

                pos_error_mag = (
                    np.linalg.norm(
                        error_vector[:3]
                    )
                )

                ori_error_mag = (
                    np.linalg.norm(
                        error_vector[3:]
                    )
                )

                if pos_error_mag < min_pos_err:

                    min_pos_err = pos_error_mag

                    best_q = np.copy(q)

                if (
                    pos_error_mag < tol
                    and
                    ori_error_mag < tol * 5
                ):

                    return q, True

                # Position fuzzy gain
                s_p, m_p, l_p = (
                    self.fuzzify_error(
                        pos_error_mag,
                        max_err=0.5
                    )
                )

                gain_xyz = (
                    self.fuzzy_gain_rules(
                        s_p,
                        m_p,
                        l_p
                    )
                )

                # Orientation fuzzy gain
                s_o, m_o, l_o = (
                    self.fuzzify_error(
                        ori_error_mag,
                        max_err=1.5
                    )
                )

                base_gain_rpy = (
                    self.fuzzy_gain_rules(
                        s_o,
                        m_o,
                        l_o
                    )
                )

                priority_factor = s_p

                gain_rpy = (
                    base_gain_rpy
                    * priority_factor
                    * 0.5
                )

                W = np.diag(
                    [
                        gain_xyz,
                        gain_xyz,
                        gain_xyz,
                        gain_rpy,
                        gain_rpy,
                        gain_rpy
                    ]
                )

                J = self.robot.jacob0(q)

                damping = 0.05

                A = (
                    J.T
                    @ W
                    @ J
                    + (
                        damping ** 2
                    ) * np.eye(
                        self.robot.n
                    )
                )

                B = (
                    J.T
                    @ W
                )

                try:

                    J_pinv = np.linalg.solve(
                        A,
                        B
                    )

                except np.linalg.LinAlgError:

                    J_pinv = np.linalg.pinv(
                        A
                    ) @ B

                dq = (
                    J_pinv
                    @ error_vector
                )

                q = q + dq

                if self.robot.qlim is not None:

                    q = np.clip(
                        q,
                        self.robot.qlim[0],
                        self.robot.qlim[1]
                    )

        return best_q, False
